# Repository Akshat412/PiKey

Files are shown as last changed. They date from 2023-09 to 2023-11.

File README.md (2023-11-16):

# PiKey
This is a SoM (System-on-Module) for the RP2040 microcontroller from Raspberry Pi. The module is based on a 2242 M.2 B+M card (2.2 cm x 4.2 cm) and can be plugged into M.2 B or M connectors.

The module can be used for any project requiring a microcontroller, and would save a lot of time in board design and assembly as well as cost, as it implements all of the required peripherals for working with an RP2040 microcontroller. Any projects using this would just need to be carrier boards for this SoM. This was inspired by Phil's Lab, who made a similar module for an STM32, and timonsku, who made a similar module for the RP2040 and also open-sourced the M.2 card footprint for KiCad! 

<p align="center">
  
</p>

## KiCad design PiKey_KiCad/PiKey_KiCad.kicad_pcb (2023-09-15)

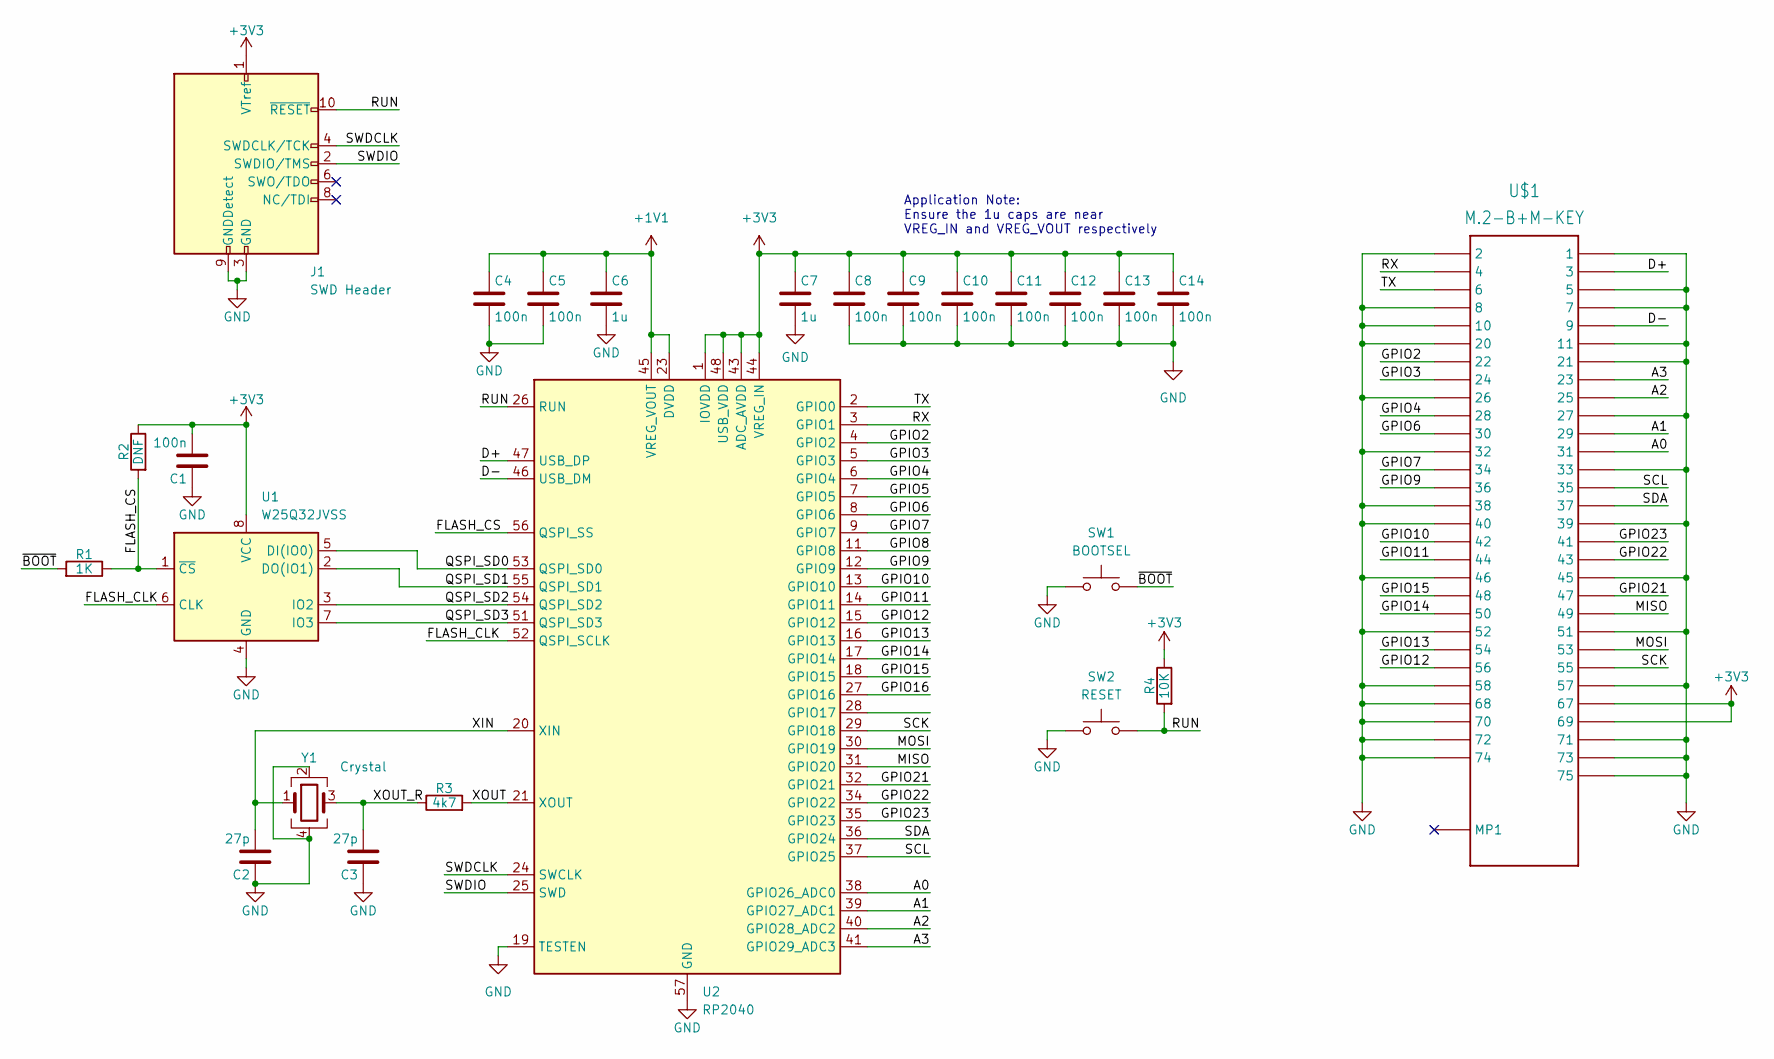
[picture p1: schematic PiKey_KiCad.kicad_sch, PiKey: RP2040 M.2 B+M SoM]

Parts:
C1: 100n; C_0603_1608Metric_Pad1.08x0.95mm_HandSolder
C2, C3: 27p; C_0603_1608Metric_Pad1.08x0.95mm_HandSolder
C4, C5, C8, C9, C10, C11, C12, C13, C14: 100n; C_0402_1005Metric
C6, C7: 1u; C_0402_1005Metric
J1: SWD Header; PinHeader_2x05_P1.27mm_Vertical_SMD
R1: 1K; R_0603_1608Metric_Pad0.98x0.95mm_HandSolder
R2: DNF; R_0603_1608Metric_Pad0.98x0.95mm_HandSolder
R3: 4k7; R_0603_1608Metric_Pad0.98x0.95mm_HandSolder
R4: 10K; R_0603_1608Metric_Pad0.98x0.95mm_HandSolder
SW1: BOOTSEL; SW_Push_1P1T_NO_CK_KMR2
SW2: RESET; SW_Push_1P1T_NO_CK_KMR2
U1: W25Q32JVSS; SOIC-8_5.23x5.23mm_P1.27mm
U2: RP2040; QFN-56-1EP_7x7mm_P0.4mm_EP3.2x3.2mm
U$1: M.2-B+M-KEY
Y1: Crystal; Crystal_SMD_SeikoEpson_FA238-4Pin_3.2x2.5mm

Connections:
+1V1: C4.1, C5.1, C6.1, U2.23 (DVDD), U2.45 (VREG_VOUT), U2.50 (DVDD)
+3V3: C1.2, C7.1, C8.1, C9.1, C10.1, C11.1, C12.1, C13.1, C14.1, J1.1 (VTref), R2.1, R4.1, U1.8 (VCC), U2.1 (IOVDD), U2.10 (IOVDD), U2.22 (IOVDD), U2.33 (IOVDD), U2.42 (IOVDD), U2.43 (ADC_AVDD), U2.44 (VREG_IN), U2.48 (USB_VDD), U2.49 (IOVDD), U$1.P$67 (67), U$1.P$69 (69)
/A0: U2.38 (GPIO26_ADC0), U$1.P$31 (31)
/A1: U2.39 (GPIO27_ADC1), U$1.P$29 (29)
/A2: U2.40 (GPIO28_ADC2), U$1.P$25 (25)
/A3: U2.41 (GPIO29_ADC3), U$1.P$23 (23)
/D+: U2.47 (USB_DP), U$1.P$3 (3)
/D-: U2.46 (USB_DM), U$1.P$9 (9)
/FLASH_CLK: U1.6 (CLK), U2.52 (QSPI_SCLK)
/FLASH_CS: R1.1, R2.2, U1.1 (~CS), U2.56 (QSPI_SS)
/GPIO2: U2.4 (GPIO2), U$1.P$22 (22)
/GPIO3: U2.5 (GPIO3), U$1.P$24 (24)
/GPIO4: U2.6 (GPIO4), U$1.P$28 (28)
/GPIO5: U2.7 (GPIO5)
/GPIO6: U2.8 (GPIO6), U$1.P$30 (30)
/GPIO7: U2.9 (GPIO7), U$1.P$34 (34)
/GPIO8: U2.11 (GPIO8)
/GPIO9: U2.12 (GPIO9), U$1.P$36 (36)
/GPIO10: U2.13 (GPIO10), U$1.P$42 (42)
/GPIO11: U2.14 (GPIO11), U$1.P$44 (44)
/GPIO12: U2.15 (GPIO12), U$1.P$56 (56)
/GPIO13: U2.16 (GPIO13), U$1.P$54 (54)
/GPIO14: U2.17 (GPIO14), U$1.P$50 (50)
/GPIO15: U2.18 (GPIO15), U$1.P$48 (48)
/GPIO16: U2.27 (GPIO16)
/GPIO21: U2.32 (GPIO21), U$1.P$47 (47)
/GPIO22: U2.34 (GPIO22), U$1.P$43 (43)
/GPIO23: U2.35 (GPIO23), U$1.P$41 (41)
/MISO: U2.31 (GPIO20), U$1.P$49 (49)
/MOSI: U2.30 (GPIO19), U$1.P$53 (53)
/QSPI_SD0: U1.5 (DI(IO0)), U2.53 (QSPI_SD0)
/QSPI_SD1: U1.2 (DO(IO1)), U2.55 (QSPI_SD1)
/QSPI_SD2: U1.3 (IO2), U2.54 (QSPI_SD2)
/QSPI_SD3: U1.7 (IO3), U2.51 (QSPI_SD3)
/RUN: J1.10 (~RESET), R4.2, SW2.2, U2.26 (RUN)
/RX: U2.3 (GPIO1), U$1.P$4 (4)
/SCK: U2.29 (GPIO18), U$1.P$55 (55)
/SCL: U2.37 (GPIO25), U$1.P$35 (35)
/SDA: U2.36 (GPIO24), U$1.P$37 (37)
/SWDCLK: J1.4 (SWDCLK/TCK), U2.24 (SWCLK)
/SWDIO: J1.2 (SWDIO/TMS), U2.25 (SWD)
/TX: U2.2 (GPIO0), U$1.P$6 (6)
/XIN: C2.2, U2.20 (XIN), Y1.1
/XOUT: R3.2, U2.21 (XOUT)
/XOUT_R: C3.2, R3.1, Y1.3
/~BOOT: R1.2, SW1.2
GND: C1.1, C2.1, C3.1, C4.2, C5.2, C6.2, C7.2, C8.2, C9.2, C10.2, C11.2, C12.2, C13.2, C14.2, J1.3 (GND), J1.5 (GND), J1.9 (GNDDetect), SW1.1, SW2.1, U1.4 (GND), U2.19 (TESTEN), U2.57 (GND), U$1.P$1 (1), U$1.P$2 (2), U$1.P$5 (5), U$1.P$7 (7), U$1.P$8 (8), U$1.P$10 (10), U$1.P$11 (11), U$1.P$20 (20), U$1.P$21 (21), U$1.P$26 (26), U$1.P$27 (27), U$1.P$32 (32), U$1.P$33 (33), U$1.P$38 (38), U$1.P$39 (39), U$1.P$40 (40), U$1.P$45 (45), U$1.P$46 (46), U$1.P$51 (51), U$1.P$52 (52), U$1.P$57 (57), U$1.P$58 (58), U$1.P$68 (68), U$1.P$70 (70), U$1.P$71 (71), U$1.P$72 (72), U$1.P$73 (73), U$1.P$74 (74), U$1.P$75 (75), Y1.2, Y1.4

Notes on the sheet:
Application Note: Ensure the 1u caps are near VREG_IN and VREG_VOUT respectively

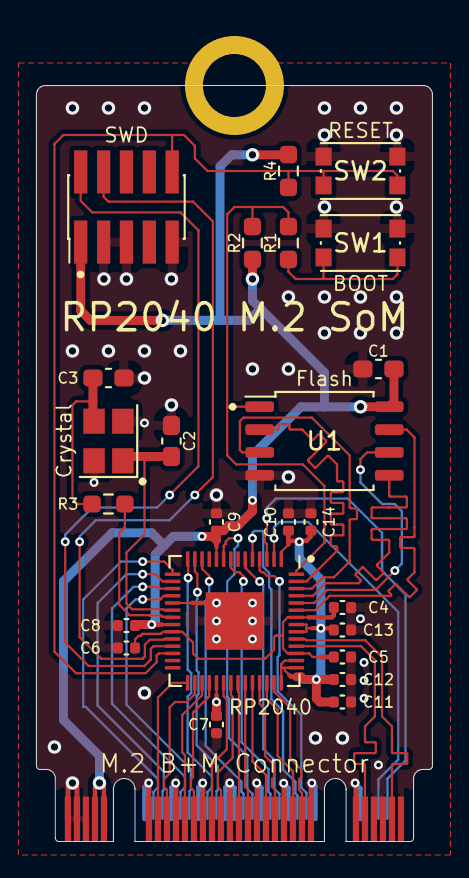
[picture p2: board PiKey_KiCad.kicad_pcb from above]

Board: 4 copper layers, 22.0 x 42.0 mm, 25 parts (0 on the bottom side), 44 nets.

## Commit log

2023-06-15 Added M.2 Connector and RP2040
    [PiKey_KiCad.kicad_pcb, PiKey_KiCad.kicad_sch]
2023-06-27 Initial routing
    Need to finish routing power and connecting GNDs together.
    [PiKey_KiCad.kicad_pcb, PiKey_KiCad.kicad_sch]
2023-07-15 Delay matching and stitching vias
    [PiKey_KiCad.kicad_pcb, PiKey_KiCad.kicad_sch]
2023-07-27 Redid M.2 signals on back
    [PiKey_KiCad.kicad_pcb, PiKey_KiCad.kicad_sch]
2023-09-03 Improved silkscreen
    [PiKey_KiCad.kicad_pcb]
2023-09-11 PR revision 2
    Fixed 3D model of board, added test points
    [PiKey_KiCad.kicad_pcb]
2023-09-15 Fixed page settings, added BOM
    [PiKey_KiCad.kicad_pcb, PiKey_KiCad.kicad_sch]
